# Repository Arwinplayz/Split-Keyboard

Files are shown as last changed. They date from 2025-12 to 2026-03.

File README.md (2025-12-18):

# Split-Keyboard
A custom **split keyboard** project built with kicad, fusion 360 and kmk.
---

## Project Overview

This keyboard is a **split design**, fully programmable using KMK firmware. The goal was to design something that would provide a decent typing experience and replace my current keyboard.
---

## Screenshots

### 1. Overall
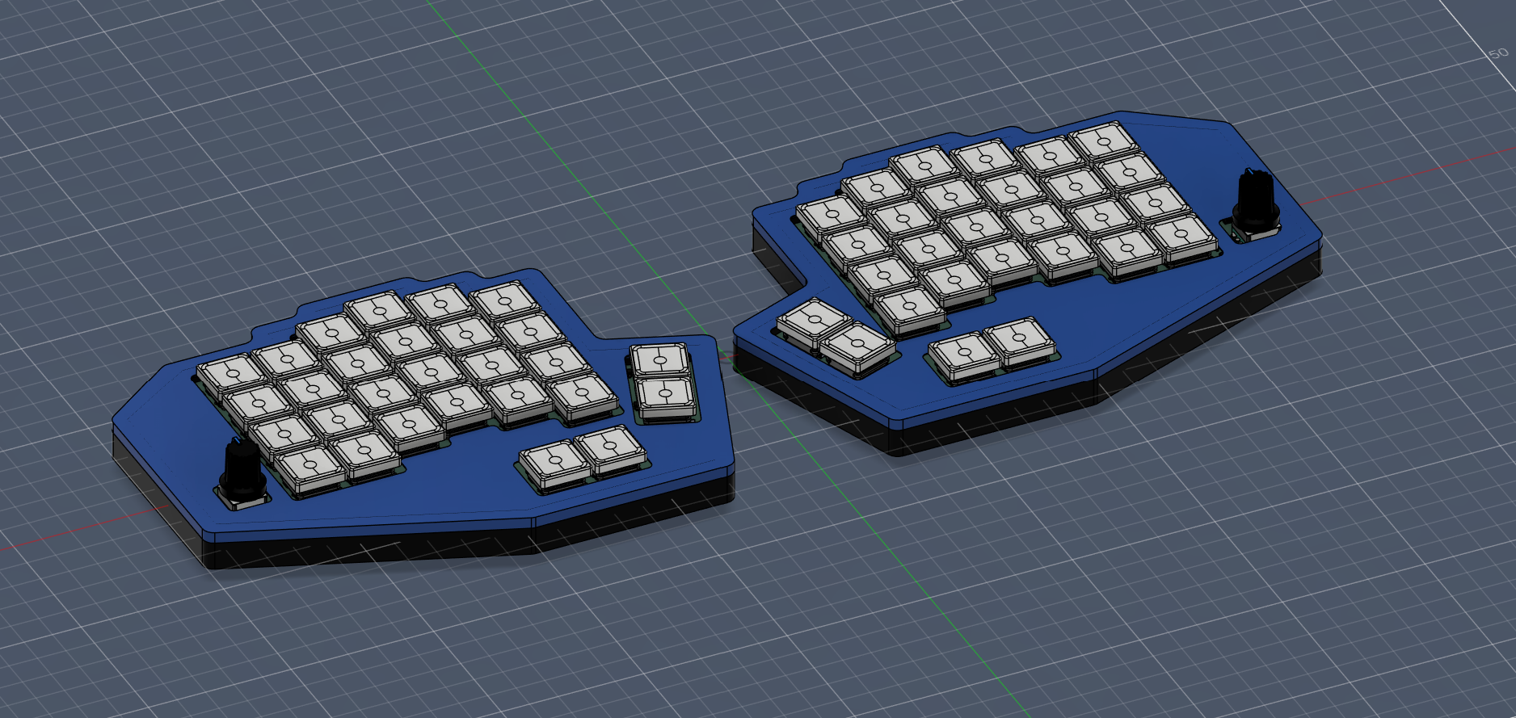
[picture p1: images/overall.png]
Hackpad Screenshot
  

### 2. Schematic
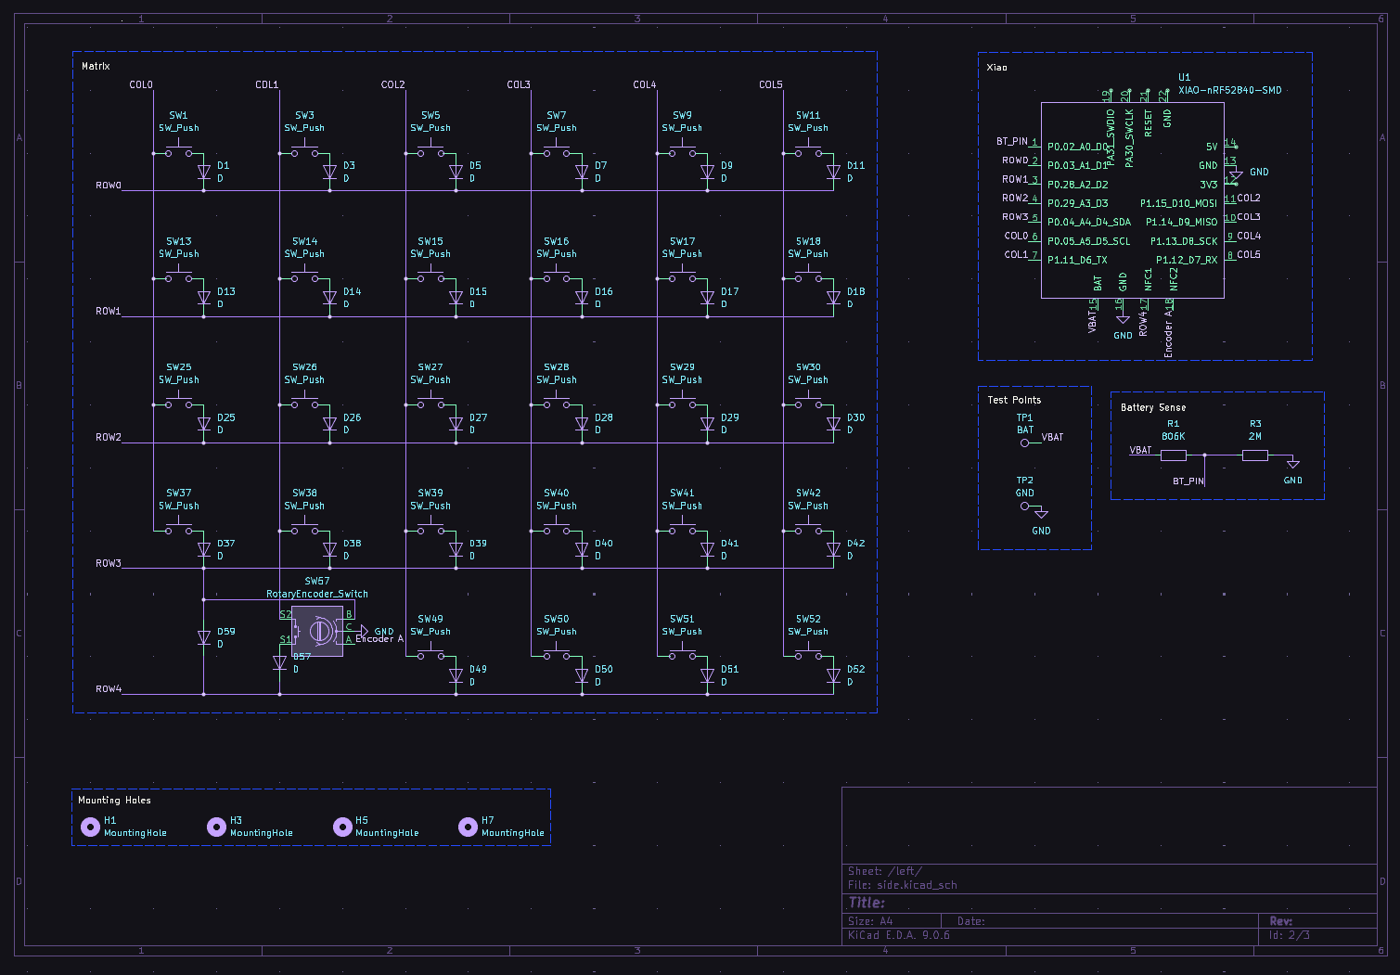
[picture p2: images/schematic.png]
Schematic Screenshot
  

### 3. PCB layout
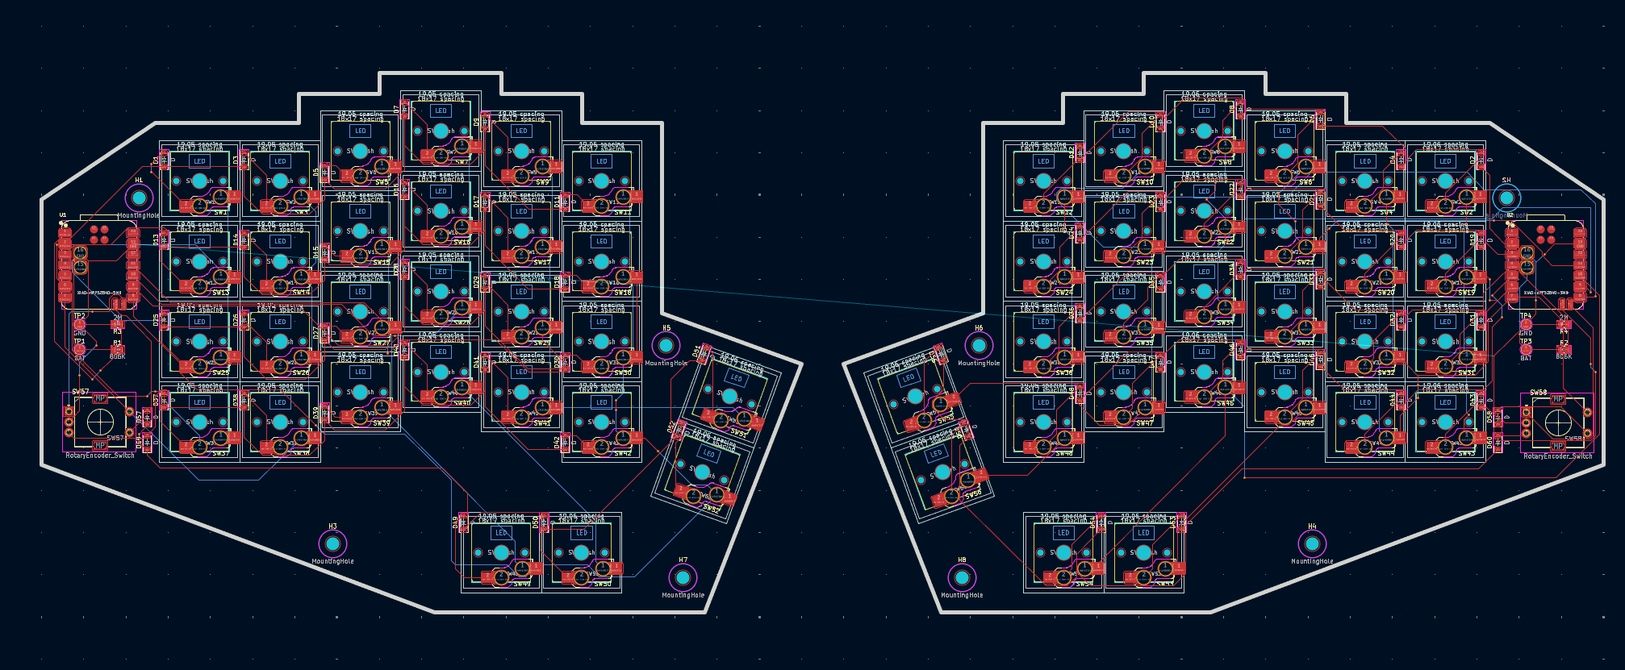
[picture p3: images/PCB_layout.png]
PCB Screenshot
  

### 4. Case Assembly
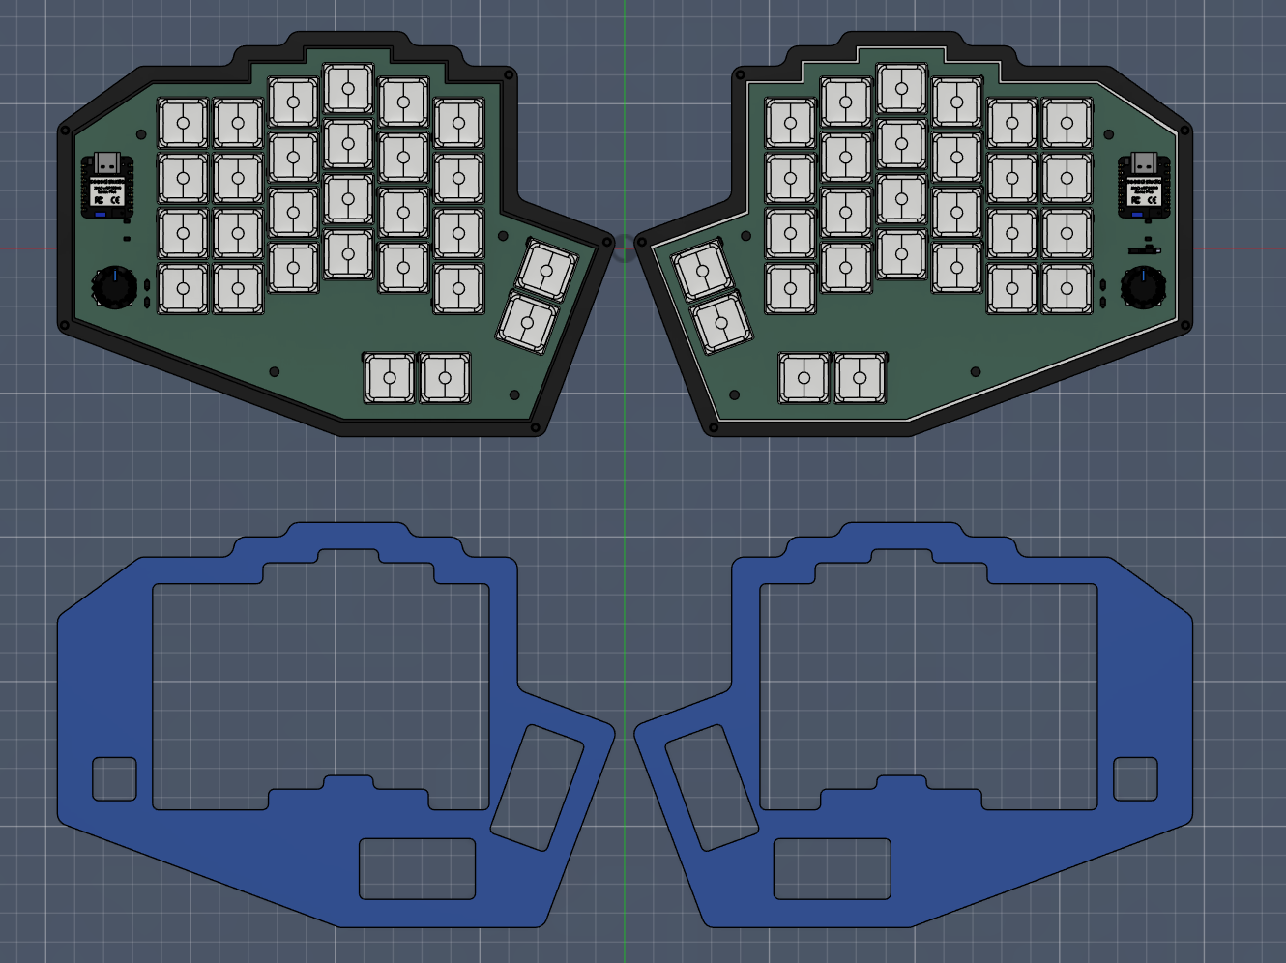
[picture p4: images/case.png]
Case Screenshot
  

### Bill Of Materials

| Item | Description | Qty | Unit Price (AUD) | Total Price (AUD) | URL | Running Total (AUD) | USD |
|---|---|-----|---|---|-----|---|-----|
| Kailh Choc Hotswap Socket x10 | Hotswap socket | 1 | $1.52 | $1.52 | [AliExpress](https://www.aliexpress.com/item/1005009439757444.html) | $1.52 | $1.00 |
| Rotary Encoder Module EC11 | Rotary encoder with knob | 2 | $0.43 | $0.86 | [Alibaba](https://www.alibaba.com/product-detail/Yuwah-Factory-Sale-Linear-rotary-Encoder_1601398686693.html) | $2.38 | $1.57 |
| Rotary Encoder Control Button Knob | Rotary encoder knob | 2 | $3.14 | $6.28 | [AliExpress](https://www.aliexpress.com/item/1005002930536102.html) | $8.66 | $5.71 |
| Kailh Low Profile Choc Brown (30 pack) | Switches | 2 | $27.99 | $55.98 | [AliExpress](https://www.aliexpress.com/item/1005005970877769.html) | $58.36 | $38.51 |
| Kailh CHOC Slim Keycaps – Milky White (10 pack) | Keycaps | 2 | $15.69 | $31.38 | [AliExpress](https://www.aliexpress.com/item/1005009153609513.html) | $89.74 | $59.21 |
| 402050 LiPo Battery | Battery | 2 | $3.80 | $7.60 | [AliExpress](https://www.aliexpress.com/item/32662701530.html) | $97.34 | $64.23 |
| JLCPCB Manufacturing | PCB | 1 | $33.00 | $33.00 | [JLCPCB](https://cart.jlcpcb.com/quote) | $130.34 | $86.04 |
| 3D Printed Case | Case | 1 | – | – | – | $130.34 | $86.04 |

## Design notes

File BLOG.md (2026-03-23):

This was from a V2 of a kyeboard I made online but ultimately wasn't able to build physically. Below I have my journel. I have learn so much about kicad and have definitely learnt from my mistakes. At one point I even went down a rabbit hole of chirality and now I know to make sure they are on the correct side of the PCB.

<!--
  This journal is auto generated by Hack Club Blueprint.
-->

# 1/8/2026 - Planning

_Time spent: 1.0h_

I recently got my PCB from JLCPCB but I realised that I had accidentally inverted the holes for the hotswap sockets. This makes it physically impossible for me to actually assembly it properly. (Awkward placement + overlap with other components)



Learning from my failures, I decided to make a V2 which would not only fix the socket problem but also allow me to redo/refine some features. That is I want to add a LiPo battery and change the requirement of having both sides plugged in separately to the PC. I already have the parts to build the keyboard so the grant is only for the PCB (and possibly extra stuff such as LiPo battery, resistors, JST PH connectors, etc)

GOALS:

- Fix hotswap socket orientation
- Added better connectivity between the split keyboards (Master and Slave RP2040)
- Add support for 1s 3.4V LiPo Battery

# 1/9/2026 12 PM - Heavily Modified Schematic

_Time spent: 2.0h_

So firstly, I realised that to use the master and slave approach, I needed a TRRS which connects the halves via UART. This meant that I needed a UART_TX, UART_RX but all my gpio pins were occupied. After some research I found that the nice!nano v2 was a good choice as it had the same Nordic chip. This allowed for bluetooth connection, a built in linear Li-Po charging circuit which helps avoid clutter. Furthermore, I added a 2 pin JST-PH connector for the Li-Po battery. There is also an RGB LED which will signal green for charged, yellow for 50$, red for low and blue for charging.





# 1/9/2026 6 PM - Routed half the PCB

_Time spent: 4.5h_

So I managed to route half the PCB now. There were many problems related to footprints as the Nice!Nano doesn't really have a goof publicly available one and so I had to design it myself. Also I added LED lights for every switch and ensured the hotswap sockets were orientated the right way.




# 1/10/2026 12 AM - Finished Routing the PCB

_Time spent: 2.0h_

So it took me a while to figure out how to mirror the left side. There was no easy way to do so I ended up flipping the edgecut and then redoing all the wiring. There is only 1 error on the ERC which is the left and right side aren't connected by this will get fixed with a TRRC cable.



# 1/10/2026 2:07 PM - Gerber Files

_Time spent: 0.5h_

I decided to get PCBA due to the keybaord requiring several LED and Diodes which all require a certain orientation to work properly. A few components require PCBA to be placed. I do have 1 or 2 components which I will hand solder myself to help reduce the costs. The PCB was too large for PCBA so I have to order each half of the PCB seperately.






P.S UPS Worldwide Express Saver was the cheapest shipping, If overall the price is too high for funding, i am willing to pay for some things.

# 1/10/2026 2:11 PM - BOM

_Time spent: 1.0h_

So since I already have most of the components such as rotary encoder, key switches, keycaps, etc, the BOM is prely for the parts I need for the PCB (the extra stuff that I didn't solder from JLC). So the total comes to about 227.98 USD. I really do not know how to make it cheaper as I've sourced everything from the cheapest sites I could find i.e aliexpress.


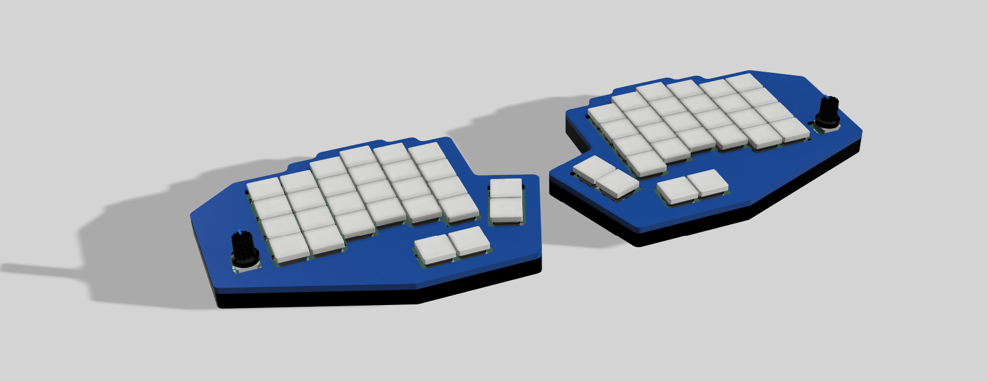
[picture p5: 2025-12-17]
images/overall_render.png

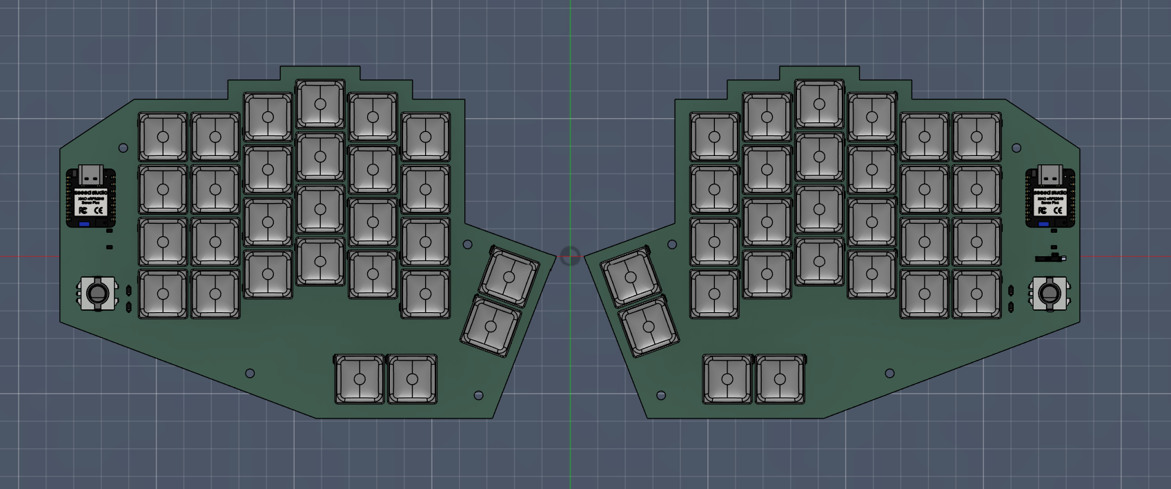
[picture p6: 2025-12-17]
images/progess_2.png

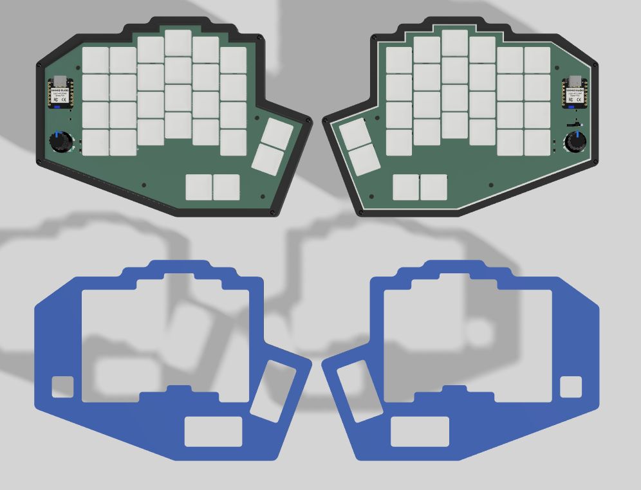
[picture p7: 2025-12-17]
images/case_render.png

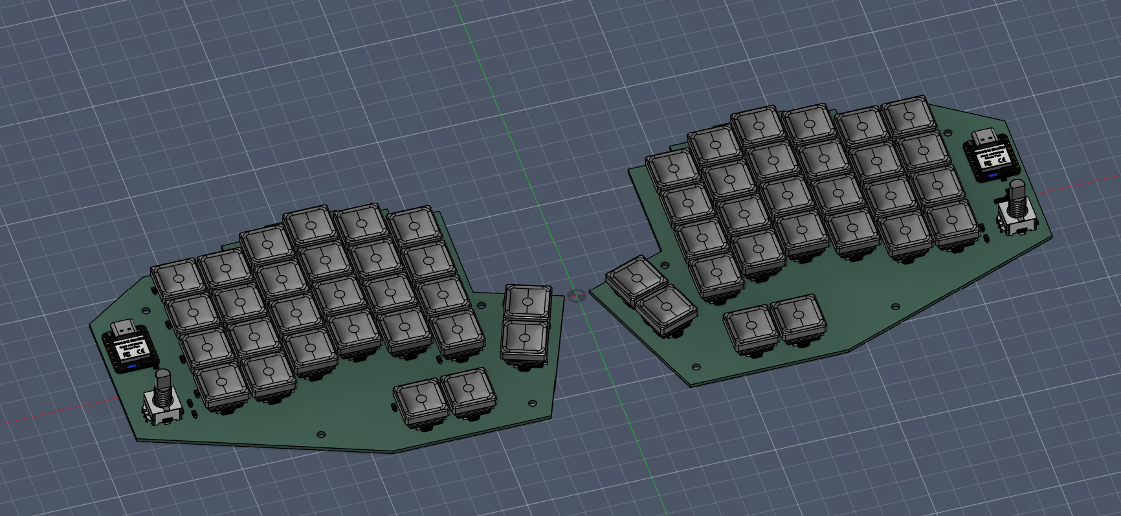
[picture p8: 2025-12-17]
images/progress.png

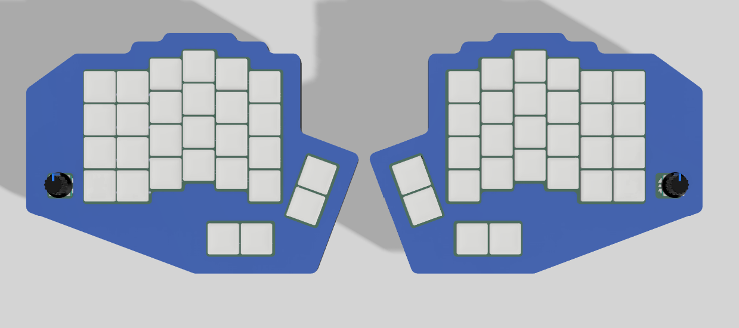
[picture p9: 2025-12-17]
images/overall_render_2.png

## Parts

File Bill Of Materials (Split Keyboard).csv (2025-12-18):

Item | Description | Quantity | Unit Price ($ AUD) | Total Price ($ AUD) | URL | Running Total | USD
Kailh Choc Hotswap Socket x 10 | Hotswap socket | 1 | $1.52 | $1.52 | https://www.aliexpress.com/item/1005009439757444.html?curPageLogUid=KVOrrHcm64qd | $1.52 | $1.00
Rotary Encoder Modules EC11 Digital Potentiometer Push Button Switch | rotary encoder with knob | 2 | $0.43 | $0.86 | https://www.alibaba.com/product-detail/Yuwah-Factory-Sale-Linear-rotary-Encoder_1601398686693.html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 | $2.38 | $1.57
Rotary Encoder Control Button Knob | Rotary encoder Knob | 2 | $3.14 | $6.28 | https://www.aliexpress.com/item/1005002930536102.html?curPageLogUid=OBDDqWBcPzPk | $8.66 | $5.72
Kailh Low Profile Choc Brown - 30 pack | Switches | 2 | $27.99 | $55.98 | https://www.aliexpress.com/item/1005005970877769.html?curPageLogUid=NkXyOHacaJCo | $58.36 | $38.52
Kailh CHOC Slim Keycaps - Milky White - 10 pack | Keycaps | 2 | $15.69 | $31.38 | https://www.aliexpress.com/item/1005009153609513.html?curPageLogUid=ATfqa91LW3Zl | $89.74 | $59.24
402050 LiPo | Battery | 2 | $3.80 | $7.60 | https://www.aliexpress.com/p/tesla-landing/index.html?productId=32662701530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 | $97.34 | $64.26
JLCPCB manufacturing | PCB | 1 | $33.00 | $33.00 | https://cart.jlcpcb.com/quote?stencilLayer=2&stencilWidth=180&stencilLength=130&stencilCounts=5&plateType | $130.34 | $86.04
3D printed case | Case | 1 | - | - | - | $130.34 | $86.04

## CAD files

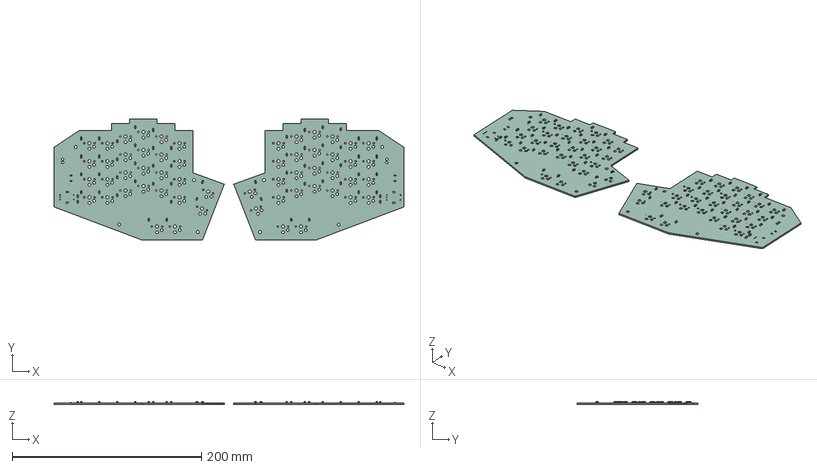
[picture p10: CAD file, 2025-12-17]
PCB/Split keyboard.step
370.0 x 128.0 x 2.85 mm
D_SOD-123 x 60
R_0805_2012Metric x 4
Split keyboard_PCB_1
Split keyboard_PCB_2

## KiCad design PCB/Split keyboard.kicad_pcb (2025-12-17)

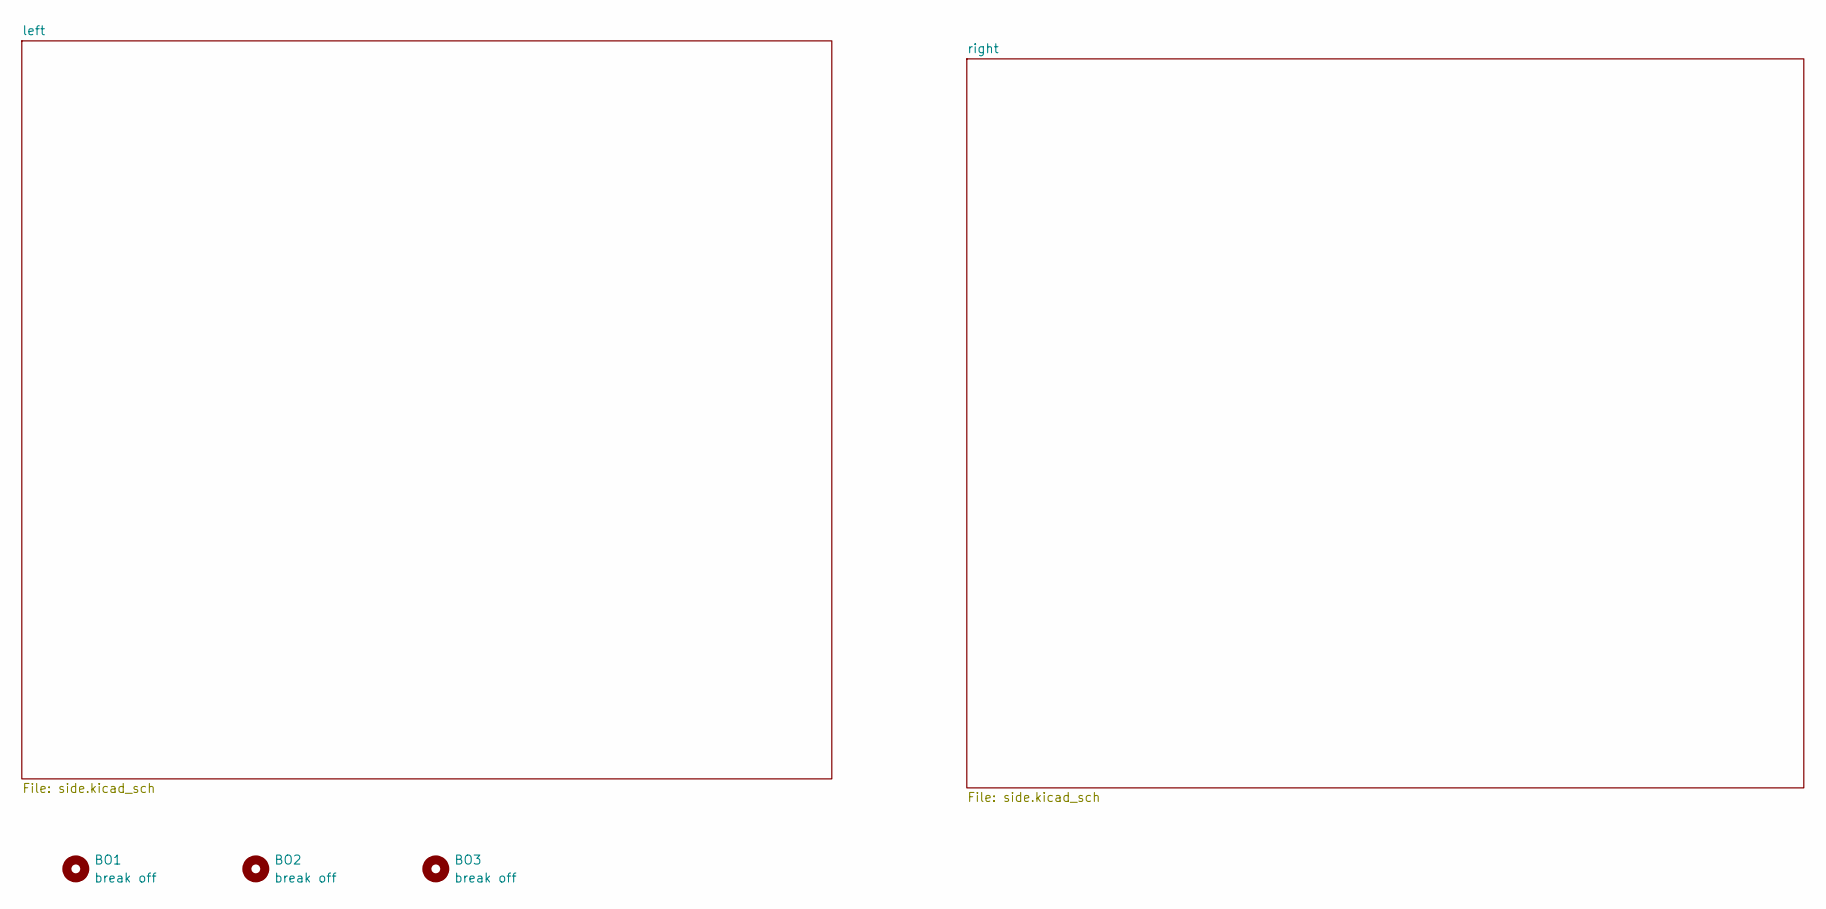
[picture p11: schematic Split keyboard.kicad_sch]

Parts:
BO1, BO2, BO3: break off; mouse-bite-5mm-slot

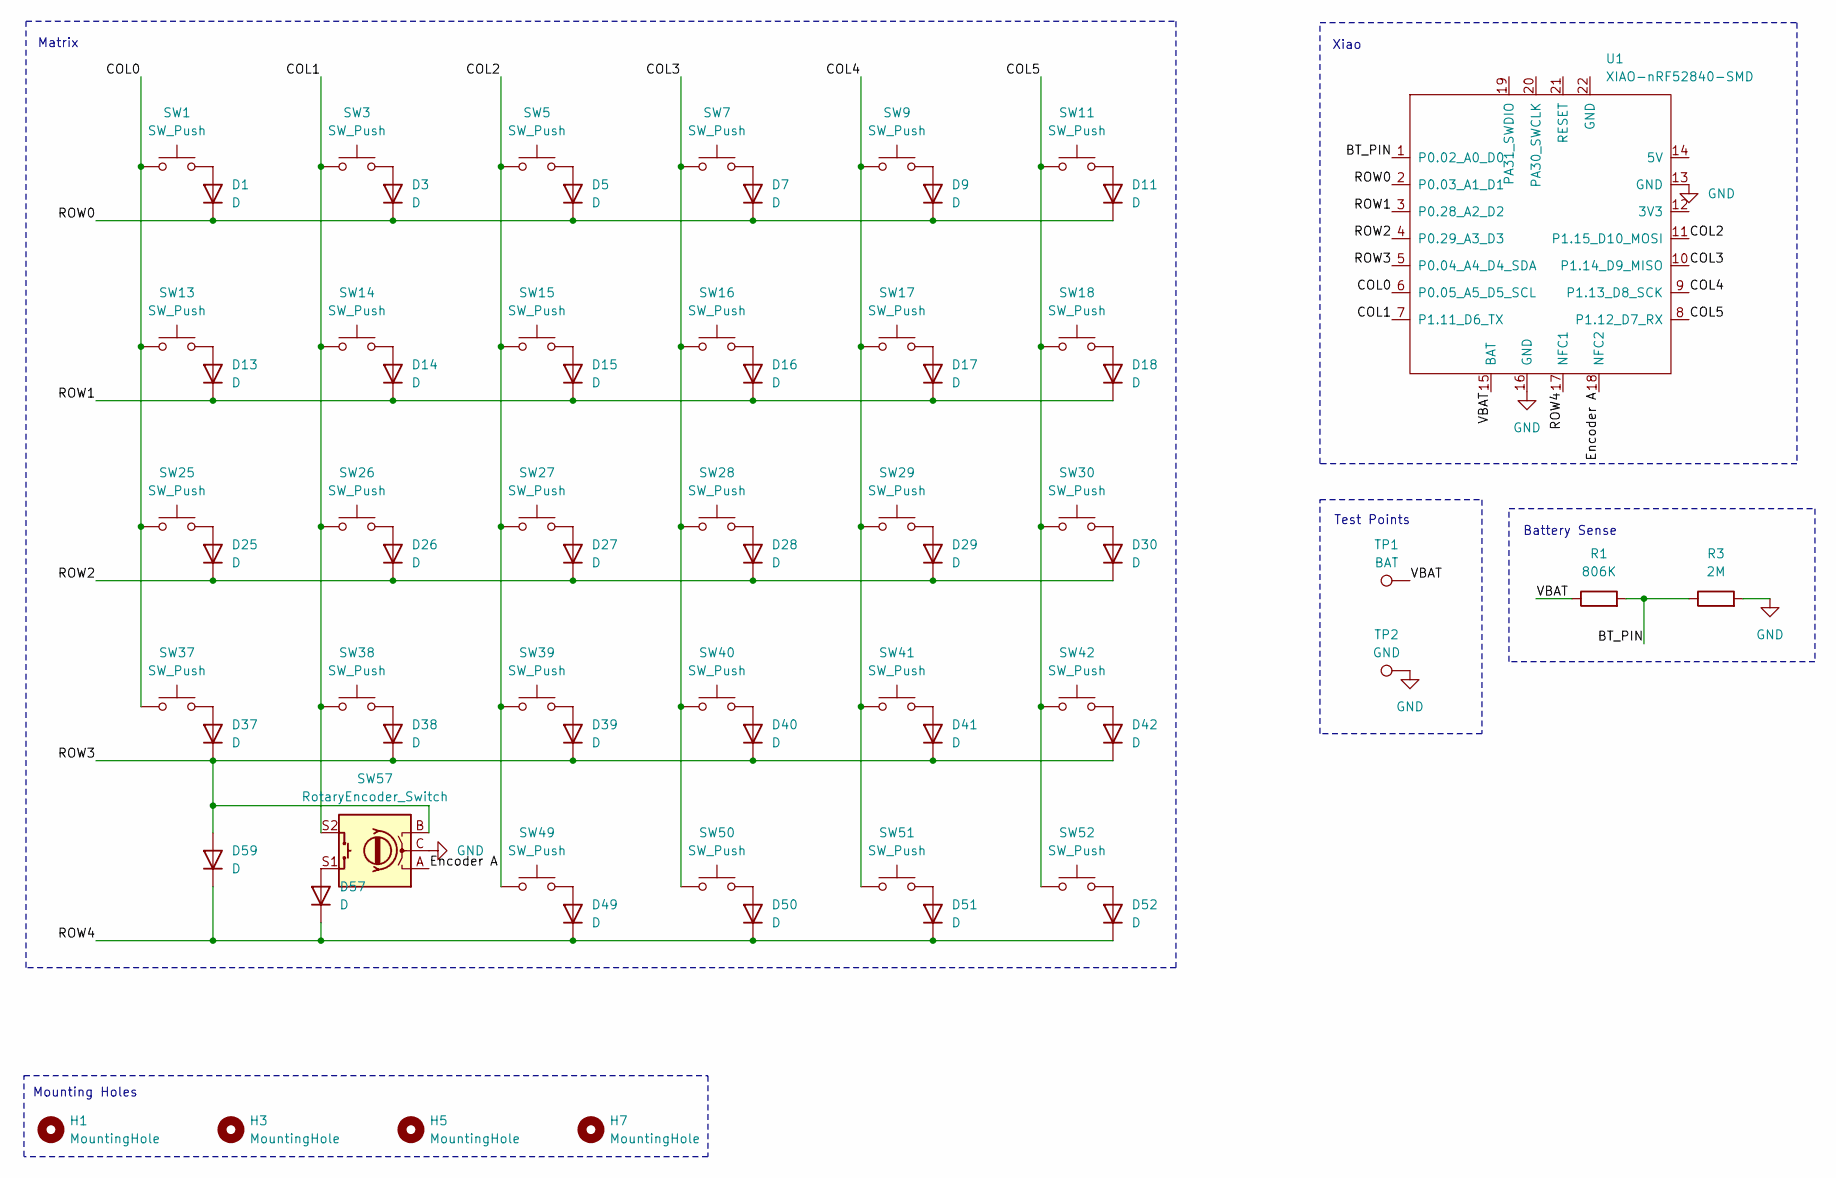
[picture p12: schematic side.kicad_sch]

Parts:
D1, D3, D5, D7, D9, D11, D13, D14, D15, D16, D17, D18, D25, D26, D27, D28, D29, D30, D37, D38, D39, D40, D41, D42, D49, D50, D51, D52, D57, D59: D; D_SOD-123
H1, H3, H5, H7: MountingHole; MountingHole_3.2mm_M3
R1: 806K; R_0805_2012Metric
R3: 2M; R_0805_2012Metric
SW1, SW3, SW5, SW7, SW9, SW11, SW13, SW14, SW15, SW16, SW17, SW18, SW25, SW26, SW27, SW28, SW29, SW30, SW37, SW38, SW39, SW40, SW41, SW42, SW49, SW50, SW51, SW52: SW_Push; SW_choc_v1_HS_CPG135001S30_1u
SW57: RotaryEncoder_Switch; RotaryEncoder_Alps_EC11E-Switch_Vertical_H20mm
TP1: BAT; TestPoint_Pad_D2.0mm
TP2: GND; TestPoint_Pad_D2.0mm
U1: XIAO-nRF52840-SMD; modified-XIAO-nRF52840-SMD

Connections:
/left/BT_PIN: R1.2, R3.1, U1.1 (P0.02_A0_D0)
/left/COL0: SW1.1, SW13.1, SW25.1, SW37.1, U1.6 (P0.05_A5_D5_SCL)
/left/COL1: SW3.1, SW14.1, SW26.1, SW38.1, SW57.S2, U1.7 (P1.11_D6_TX)
/left/COL2: SW5.1, SW15.1, SW27.1, SW39.1, SW49.1, U1.11 (P1.15_D10_MOSI)
/left/COL3: SW7.1, SW16.1, SW28.1, SW40.1, SW50.1, U1.10 (P1.14_D9_MISO)
/left/COL4: SW9.1, SW17.1, SW29.1, SW41.1, SW51.1, U1.9 (P1.13_D8_SCK)
/left/COL5: SW11.1, SW18.1, SW30.1, SW42.1, SW52.1, U1.8 (P1.12_D7_RX)
/left/Encoder A: SW57.A, U1.18 (NFC2)
/left/ROW0: D1.1 (K), D3.1 (K), D5.1 (K), D7.1 (K), D9.1 (K), D11.1 (K), U1.2 (P0.03_A1_D1)
/left/ROW1: D13.1 (K), D14.1 (K), D15.1 (K), D16.1 (K), D17.1 (K), D18.1 (K), U1.3 (P0.28_A2_D2)
/left/ROW2: D25.1 (K), D26.1 (K), D27.1 (K), D28.1 (K), D29.1 (K), D30.1 (K), U1.4 (P0.29_A3_D3)
/left/ROW3: D37.1 (K), D38.1 (K), D39.1 (K), D40.1 (K), D41.1 (K), D42.1 (K), D59.2 (A), SW57.B, U1.5 (P0.04_A4_D4_SDA)
/left/ROW4: D49.1 (K), D50.1 (K), D51.1 (K), D52.1 (K), D57.1 (K), D59.1 (K), U1.17 (NFC1)
/left/VBAT: R1.1, TP1.1, U1.15 (BAT)
GND: R3.2, SW57.C, TP2.1, U1.13 (GND), U1.16 (GND); also elsewhere on the board
unnamed: D1.2 (A), SW1.2
unnamed: D3.2 (A), SW3.2
unnamed: D5.2 (A), SW5.2
unnamed: D7.2 (A), SW7.2
unnamed: D9.2 (A), SW9.2
unnamed: D11.2 (A), SW11.2
unnamed: D13.2 (A), SW13.2
unnamed: D14.2 (A), SW14.2
unnamed: D15.2 (A), SW15.2
unnamed: D16.2 (A), SW16.2
unnamed: D17.2 (A), SW17.2
unnamed: D18.2 (A), SW18.2
unnamed: D25.2 (A), SW25.2
unnamed: D26.2 (A), SW26.2
unnamed: D27.2 (A), SW27.2
unnamed: D28.2 (A), SW28.2
unnamed: D29.2 (A), SW29.2
unnamed: D30.2 (A), SW30.2
unnamed: D37.2 (A), SW37.2
unnamed: D38.2 (A), SW38.2
unnamed: D39.2 (A), SW39.2
unnamed: D40.2 (A), SW40.2
unnamed: D41.2 (A), SW41.2
unnamed: D42.2 (A), SW42.2
unnamed: D49.2 (A), SW49.2
unnamed: D50.2 (A), SW50.2
unnamed: D51.2 (A), SW51.2
unnamed: D52.2 (A), SW52.2
unnamed: D57.2 (A), SW57.S1

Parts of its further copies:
D2, D4, D6, D8, D10, D12, D19, D20, D21, D22, D23, D24, D31, D32, D33, D34, D35, D36, D43, D44, D45, D46, D47, D48, D53, D54, D55, D56, D58, D60: D; D_SOD-123
H2, H4, H6, H8: MountingHole; MountingHole_3.2mm_M3
R2: 806K; R_0805_2012Metric
R4: 2M; R_0805_2012Metric
SW2, SW4, SW6, SW8, SW10, SW12, SW19, SW20, SW21, SW22, SW23, SW24, SW31, SW32, SW33, SW34, SW35, SW36, SW43, SW44, SW45, SW46, SW47, SW48, SW53, SW54, SW55, SW56: SW_Push; SW_choc_v1_HS_CPG135001S30_1u
SW58: RotaryEncoder_Switch; RotaryEncoder_Alps_EC11E-Switch_Vertical_H20mm
TP3: BAT; TestPoint_Pad_D2.0mm
TP4: GND; TestPoint_Pad_D2.0mm
U2: XIAO-nRF52840-SMD; modified-XIAO-nRF52840-SMD

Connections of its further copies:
/right/BT_PIN: R2.2, R4.1, U2.1 (P0.02_A0_D0)
/right/COL0: SW2.1, SW19.1, SW31.1, SW43.1, U2.6 (P0.05_A5_D5_SCL)
/right/COL1: SW4.1, SW20.1, SW32.1, SW44.1, SW58.S2, U2.7 (P1.11_D6_TX)
/right/COL2: SW6.1, SW21.1, SW33.1, SW45.1, SW53.1, U2.11 (P1.15_D10_MOSI)
/right/COL3: SW8.1, SW22.1, SW34.1, SW46.1, SW54.1, U2.10 (P1.14_D9_MISO)
/right/COL4: SW10.1, SW23.1, SW35.1, SW47.1, SW55.1, U2.9 (P1.13_D8_SCK)
/right/COL5: SW12.1, SW24.1, SW36.1, SW48.1, SW56.1, U2.8 (P1.12_D7_RX)
/right/Encoder A: SW58.A, U2.18 (NFC2)
/right/ROW0: D2.1 (K), D4.1 (K), D6.1 (K), D8.1 (K), D10.1 (K), D12.1 (K), U2.2 (P0.03_A1_D1)
/right/ROW1: D19.1 (K), D20.1 (K), D21.1 (K), D22.1 (K), D23.1 (K), D24.1 (K), U2.3 (P0.28_A2_D2)
/right/ROW2: D31.1 (K), D32.1 (K), D33.1 (K), D34.1 (K), D35.1 (K), D36.1 (K), U2.4 (P0.29_A3_D3)
/right/ROW3: D43.1 (K), D44.1 (K), D45.1 (K), D46.1 (K), D47.1 (K), D48.1 (K), D60.2 (A), SW58.B, U2.5 (P0.04_A4_D4_SDA)
/right/ROW4: D53.1 (K), D54.1 (K), D55.1 (K), D56.1 (K), D58.1 (K), D60.1 (K), U2.17 (NFC1)
/right/VBAT: R2.1, TP3.1, U2.15 (BAT)
GND: R4.2, SW58.C, TP4.1, U2.13 (GND), U2.16 (GND); also elsewhere on the board
unnamed: D2.2 (A), SW2.2
unnamed: D4.2 (A), SW4.2
unnamed: D6.2 (A), SW6.2
unnamed: D8.2 (A), SW8.2
unnamed: D10.2 (A), SW10.2
unnamed: D12.2 (A), SW12.2
unnamed: D19.2 (A), SW19.2
unnamed: D20.2 (A), SW20.2
unnamed: D21.2 (A), SW21.2
unnamed: D22.2 (A), SW22.2
unnamed: D23.2 (A), SW23.2
unnamed: D24.2 (A), SW24.2
unnamed: D31.2 (A), SW31.2
unnamed: D32.2 (A), SW32.2
unnamed: D33.2 (A), SW33.2
unnamed: D34.2 (A), SW34.2
unnamed: D35.2 (A), SW35.2
unnamed: D36.2 (A), SW36.2
unnamed: D43.2 (A), SW43.2
unnamed: D44.2 (A), SW44.2
unnamed: D45.2 (A), SW45.2
unnamed: D46.2 (A), SW46.2
unnamed: D47.2 (A), SW47.2
unnamed: D48.2 (A), SW48.2
unnamed: D53.2 (A), SW53.2
unnamed: D54.2 (A), SW54.2
unnamed: D55.2 (A), SW55.2
unnamed: D56.2 (A), SW56.2
unnamed: D58.2 (A), SW58.S1

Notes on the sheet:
Xiao
Battery Sense
Mounting Holes
Matrix
Test Points

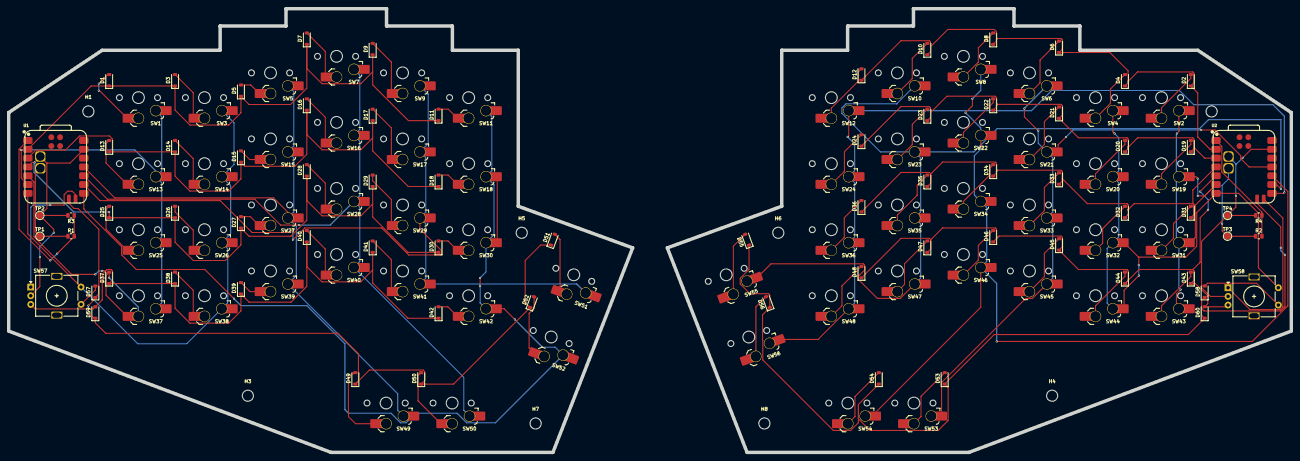
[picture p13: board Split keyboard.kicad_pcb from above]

Board: 2 copper layers, 370.0 x 128.0 mm, 136 parts (1 on the bottom side), 87 nets.

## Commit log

2025-12-17 Add local project files
    [Split keyboard.kicad_pcb, Split keyboard.kicad_sch, Split keyboard.step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]
2025-12-17 Added BOM
    [Bill Of Materials (Split Keyboard).csv]
2025-12-17 Add Bill of Materials section to README
    Added a Bill of Materials (BOM) section with item details, quantities, prices, and URLs.
2025-12-17 Update Bill of Materials with new pricing and items
    [Bill Of Materials (Split Keyboard).csv]
2025-12-17 Revise Bill of Materials with updated items and prices
    Updated the Bill of Materials (BOM) section with new items and pricing, including USD conversions.
2025-12-18 Revise quantities and prices in BOM for keyboard
    Updated quantities and prices for various components in the Bill of Materials.
    [Bill Of Materials (Split Keyboard).csv]
2025-12-18 Update Bill Of Materials with new item details
2025-12-18 Update Bill Of Materials (Split Keyboard).csv
    [Bill Of Materials (Split Keyboard).csv]
